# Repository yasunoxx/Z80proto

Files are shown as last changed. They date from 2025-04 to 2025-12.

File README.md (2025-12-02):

# Z80proto2 -- I/O processor, implementation for Z80

## !!!CAUTION!!!
- MiniLoaderとMiniMon-Cは、sdccに移行するための作業中です。モニタ/ローダとしてはMiniMonを使用して下さい。

## What is this?(コレは何？)
- ev68020などで使うつもりの、I/OプロセッサのZ80実装です。CP/M-68kなどの移植を視野に入れて、CP/M80を動かす事をゴールにしています。ソレゆえに、Z80proto2では64kフルRAMにする回路(ROMKICK)を含みます。

## Environment(動作環境)
Tool                    | Description
:-----------------------|:---------------------------------------------------
**target**              | Z80(Z80proto2), Z84C(SAKI80), and other Z80 compat. see sch [Z80proto/sch](https://github.com/yasunoxx/Z80proto/sch) folder
**z88dk**               | v19766-9ffe2042c-20220723
**make**                | GNU Make 4.3, Built for x86_64-pc-linux-gnu
**CAD**                 | KiCad Version (6.0.11), release build

## Status(進捗) -- 2025年4月現在
Hardware                          | Description
:---------------------------------|:-----------------------------------------
Z80proto2 board                   |設計完了, FDC&DMAモジュールの試作中
Z80proto2 SAKI80(AKA Super AKI-80) support board|設計完了, 試作回路のデバッグ中

Software           | Description
:------------------|:--------------------------------------------------------
ipl0               |デバッグ完了。MiniMonのbuildに必要
MiniMon            |MiniLoaderの拡張バージョン。ゆえにstatusはMiniLoaderと同様。機能追加中(FDC関連)&SAKI80対応作業中
MiniMon-C          |MiniMonのCバージョン。sdccに移行作業中
Miniloader         |フレームワークは完了, sdccに移行作業中

Additional         | Description
:------------------|:--------------------------------------------------------
MSP430_SPI_LCD40x4 |設計完了, SPIターゲット機能デバッグ中
freertos           |実験的実装(EXPERIMENTAL), 動作は保証しません
memtest80          |デバッグ完了。7seg表示必須(ゆえにSAKI80非対応)

## TODO(今後修正・追加すべきモノゴトと細かい話)
0. 開発環境をzccからsdccに移行する -> 現在作業中
1. SIOフロー制御の追加 -> DTR*をアサート/ネゲートするだけの機能追加、ではダメっぽいので、キチンとした仕様を実装する
2. 回路構成の説明書作成 -> プログラムの読解が困難と考えられるため早急に
3. TMPZ84C015BのSIO受信割込 -> 受信割込有効後1byteでフリーズする問題の原因特定(後述)
4. analyze_SIO0(z80sio_sub.asm)の簡略化 -> SIO0割込受信後の処理。現状はマジメにフラグをチェックしている。どうせエラーリカバリは上位で行うのだから、単にフラグクリアで良いのでは？
5. ソースコードコメンタリ作成

## Fixed Re-confirm(動作確認中の修正点)
- システムレジスタ(UW5)を74HC259などに変更する -> 現状74HC574には出力リセットが付いていないため(動作環境によっては問題になりうる)
- TC6367コンパチビリティ廃止によるUW2の削除 -> FIXしたつもりだけれども慎重に確認が必要 -> Proto2基板によりロングランテストで確認中
- 回路修正により、SPI_SELD_DEVは必要なくなった -> 7seg回路をオプションとしたため、そこに含まれていたSPICS*をシステムレジスタ(UW5)に移した -> ソレをU17で読み取り可能としたので、RAM上に保持する必要がなくなった

## Known Problem(既知の問題)
- TMPZ84C015BのSIOAにおいて、受信割込有効後1byteでフリーズする問題が起きています。現在、開発に使用しているデバイス単体の問題なのか、仕様の違いによる問題なのかの特定が出来ていません。そのため、getchar_SIO0サブルーチン(z80sio_sub.asm)でポーリング受信をしています。Z80SIOの受信バッファは3bytesなので、他の重い処理を行っている時にバッファオーバーランする可能性があります。この問題はZ80proto2基板(LH0085使用)では起きていません。
- SAKI80サポート基板において、現在の設計では使用部品の個体差(ゲート遅延など)によってRead/Writeが間に合わない場合があります。WAIT回路の追加を慎重に検討しています。現状では、アクセス時間の短いROM/RAMを選択する(55nsecでギリギリ？)、ゲート遅延の短いバッファを使用する(HCよりもVHCやABTがオススメ)などを検討してください。
- SIO送受信において、フロー制御が実装されていません。現状、ポーリング受信では取りこぼしや文字化けが発生します。ターミナル側で送信遅延(10~20msec/char)を調整すると良いようです。proto2用SIO＆CTCモジュールとSAKI80にはDTR/DSR配線が存在するので、ハードフローを実装する予定です。

## LICENSE(ライセンス)
- ソースツリーには、FreeRTOS-Kernel(FreeRTOSv202406.01-LTS)の一部が含まれています。
 [FreeRTOS/FreeRTOS](https://github.com/FreeRTOS/FreeRTOS)
- 使用しているデバイスについて、メーカーがデータシートなどで開示している技術情報は、各社に工業所有権があります。
- kermit-suspend.cは、Frank da Cruz氏によるkermit.basをCに移植したものです。
- xymodem.cは、Chuck Forsberg氏による10-14-88版ドキュメントより作成しました。
- "Super AKI-80"、"スーパーAKI-80"は、株式会社秋月電子通商の商標です。
- lcdlib.cは、Sakazume氏(http://219.117.208.26/~saka/ham/LCD2/)による実装です。
- xprintf.cは、CHaN氏(http://elm-chan.org/fsw.html)による実装の一部です。
- 私(yasunoxx▼Julia)が書いたプログラムは、MITライセンスで開示しています。本プログラム [Z80proto](https://github.com/yasunoxx/Z80proto)を使用した/使用しない事による全ての結果について、上記権利者と私は何の保証も賠償も致しません。

## FAQ(よくあるしつもん、そしてツッコミ)
- ROMを書く道具がない, ROMが入手できない -> 私は中華ROMライタ(TL866Ⅱ plus)をハードオフで拾いました。もし、どうしてもROMを入手したい(けれどもROMライタは買いたくない)という方は、私のtwitterアカウント(@noisequeen)にDMしてみて下さい。メールは殆ど読んでいません。
- ドキュメントが無いのは何故？ -> こう見えても忙しいんです。プロジェクトがスタックしているので、詳細なドキュメントは後回しになりますね。希望者が多数になったら、ドキュメント作成のプライオリティも上がりますけれども。
- 基板は作らないの？ -> こんなの、基板を起こしても。。。もし希望者多数だとしたら、秋月さんに出してほしいなぁ(その際は、可能な限りの協力を致します)。
- ソースが読みにくい -> 私の力量不足です。読みにくいと指摘できるレベルの方は、もっとエレガントなコードが書けるハズです。さあ、書いて公開するのです。ipl0やmemtest80は読みやすい部類だと思いますけれども、まだまだですね。
- FDCマダー？ -> なかなか、モチベーションが上がらないのです。CPU&CTC&SIOまではイージーなのですけれども、特にFDCは相手が物理なので。chotto mattene.

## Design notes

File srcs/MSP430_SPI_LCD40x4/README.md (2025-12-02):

MSP430_SPI_LCD40x4
==================

- SPI input, 40x4 Character LCD output for MSP430G2553.

- Add new GCC(Mitto Systems Limited - msp430-gcc 9.2.0.50) support. https://www.ti.com/tool/MSP430-GCC-OPENSOURCE

- If you use old GCC, you must edit Makefile and interrupt func.

- for usage:

    make
    mspdebug rf2500
      > prog main.elf
      > exit

- and see sources and schematics.

- ※コレは、特にどうという事の無い実装ですわね。

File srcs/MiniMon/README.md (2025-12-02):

## MiniMon -- Mini Monitor for Z80proto w/Async. FIFO

# Usage

- build ../ipl0.bin, 'zcc +embedded --no-crt ../ipl0.asm -o ../ipl0.bin'
- and just type 'make' .

# Stats(進捗状況)
- 現在、testmode(Debug via Async FIFO)の実装中です。FT245RをLinux(or wsl2)に接続して、MiniMonプロンプトに”T”コマンドを入力し、tmhost [tmhost/tm]を実行すると、FIFOを使用したハンドシェイクらしき動作をします。
- その他、実装済コマンドはMiniLoader同様に動作します。

# ## Environment(動作環境)
Tool                    | Description
:-----------------------|:---------------------------------------------------
**target**              | Z80(Z80proto2), Z84C(SAKI80), and other Z80 compat. see also sch [Z80proto/sch](https://github.com/yasunoxx/Z80proto/sch) folder
**z88dk**               | v19766-9ffe2042c-20220723
**make**                | GNU Make 4.3, Built for x86_64-pc-linux-gnu

# Memory Map
    |                   |
----:-------------------:---------------------------------
ROM | 0 ~ 0FFh          | ipl0
ROM | 100h ~ 1FFFh      | MiniMon .text & .data area
RAM | 8000h ~ 0D7FFh    | (free)
RAM | 0D800h ~ 0E7FFh   | MiniMon .text & .data area
RAM | 0E800h ~ 0F800h   | (free, but do not touch)
RAM | 0F800h ~ 0FFFFh   | MiniMon work area
RAM | (0FC30h ~ 0FFFFh) | stack

## LICENSE(ライセンス)
- 使用しているデバイスについて、メーカーがデータシートなどで開示している技術情報は、各社に工業所有権があります。
- "Super AKI-80"、"スーパーAKI-80"は、株式会社秋月電子通商の商標です。
- lcdlib.cは、Sakazume氏(http://219.117.208.26/~saka/ham/LCD2/)による実装です。
- 私(yasunoxx▼Julia)が書いたプログラムは、MITライセンスで開示しています。本プログラム[Z80proto](https://github.com/yasunoxx/Z80proto)を使用した/使用しない事による全ての結果について、上記権利者と私は何の保証も賠償も致しません。

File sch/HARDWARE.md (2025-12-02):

# Z80proto2 hardware -- I/O processor, implementation for Z80

## What is this?(コレは何？)
- ev68020などで使うつもりの、I/OプロセッサのZ80実装です。ここでは、ハードウェアの概要を説明します。

## Environment(動作環境)
Tool                    | Description
:-----------------------|:---------------------------------------------------
**target**              | Z80(Z80proto2), Z84C(SAKI80), and other Z80 compat.
**Boot ROM**            | 2716/2816 for minimum config., 2764/2864 for Serial Download config.
**CAD**                 | KiCad Version (6.0.11), release build

## Directory(ディレクトリ構成)
Directory           | Description
:-------------------|:--------------------------------------------------
**FDC**             |MZ-80FI's diagram trace (C)1981 Sharp Corporation
**MZ80K_framebuf**  |MZ-80K's diagram trace (C)1979-81 Sharp Corporation
**Z80proto1**       |Z80proto IM1 model(project suspend)
**Z80proto2**       |Z80proto IM2 model
**Z80proto2-SAKI80**|Z80proto IM2 model w/Super AKI-80

## Status(進捗) -- 2025年4月現在
- Z80proto2基板 -> 設計完了, FDC&DMAモジュールの試作中
- Z80proto2 SAKI80(AKA Super AKI-80)サポート基板 -> 設計完了, 試作回路のデバッグ中

## Overview(概要)
- 全体的には、ごく普通のZ80回路です。クロック4MHzで150nsecのメモリがノーウェイト動作しています。SAKI80の場合は1ウェイト入れておくべきでしょう。
- 本設計の最大の特徴はROMKICK回路です。コレは、ROM領域をI/O操作によりRAMに切り替え可能としたもので、他のプロジェクトでも動作の実績があります。下記メモリマップを参照して下さい。
- 本プロジェクト(Z80proto)開始時に、東京秋葉原で容易に入手可能なRAMは容量が大きなモノばかりだったので、628128相当のM68AF127を採用しました。Z80のメモリ空間64kBytesの2倍なので、リセット後には領域の前半分64kBytesを使い、RAMKICK回路により切り替え可能としています。
- ROMKICK/RAMKICKについて。プログラム誤動作などによる切り替え動作を防ぐため、2ステップの手順が必要です。
- その他、ソフトウェアによるSPI実装(ソレに対応するI/Oピン)、7seg LED表示機能(オプション)があります。
- ROMKICK/RAMICK, SPI機能を使用しない場合は、回路を実装しなくても構いません。ROMのアドレスデコードは忘れずに。

## Memory Map(メモリマップ)
- Power or RESET*　on Z80proto2
Address    |
:----------|:--------------------------------
0000h~1FFFh| ROM
2000h~FFFFh| RAM前半 or 後半(RAMKICKで切り替え)

- ROMKICK操作後
Address    |
:----------|:--------------------------------
0000h~FFFFh| RAM前半 or 後半(RAMKICKで切り替え)

-- ROMKICK後、フルRAM状態でRAMKICKする際には、当然ながら工夫が必要です。

## TODO(今後修正・追加すべきモノゴトと細かい話)
1. 回路構成の説明書作成 -> この文書。書き足していきます
2. TC6367コンパチビリティ廃止によるUW2の削除 -> FIXしたつもりだけれども慎重に確認が必要 -> Proto2基板によりロングランテストで確認中
3. 回路修正により、SPI_SELD_DEVは必要なくなった -> 7seg回路をオプションとしたため、そこに含まれていたSPICS*をシステムレジスタ(UW5)に移した -> ソレをU17で読み取り可能としたので、RAM上に保持する必要がなくなった
4. システムレジスタ(UW5)を74HC259などに変更する -> 現状74HC574には出力リセットが付いていないため(動作環境によっては問題になりうる)

## Known Problem(既知の問題)
-  SAKI80サポート基板において、現在の設計では使用部品の個体差(ゲート遅延など)によってRead/Writeが間に合わない場合があります。WAIT回路の追加を慎重に検討しています。現状では、アクセス時間の短いROM/RAMを選択する(55nsecでギリギリ？)、ゲート遅延の短いバッファを使用する(HCよりもVHCやABTがオススメ)などを検討してください。

## Cautions(注意事項)
- 28C64を使用する場合、2764との差異により1番ピンの処置が必要になります。

## LICENSE(ライセンス)
- FDC回路の設計参考として、MZ-80KとMZ-80FIの回路図を参照させて頂きました。(C)1979-81 Sharp Corporation
- 使用しているデバイスについて、メーカーがデータシートなどで開示している技術情報は、各社に工業所有権があります。
- "Super AKI-80"、"スーパーAKI-80"は、株式会社秋月電子通商の商標です。
- 私(yasunoxx▼Julia)が書いたプログラムは、MITライセンスで開示しています。本プログラム [Z80proto2](https://github.com/yasunoxx/Z80proto2)を使用した/使用しない事による全ての結果について、上記権利者と私は何の保証も賠償も致しません。

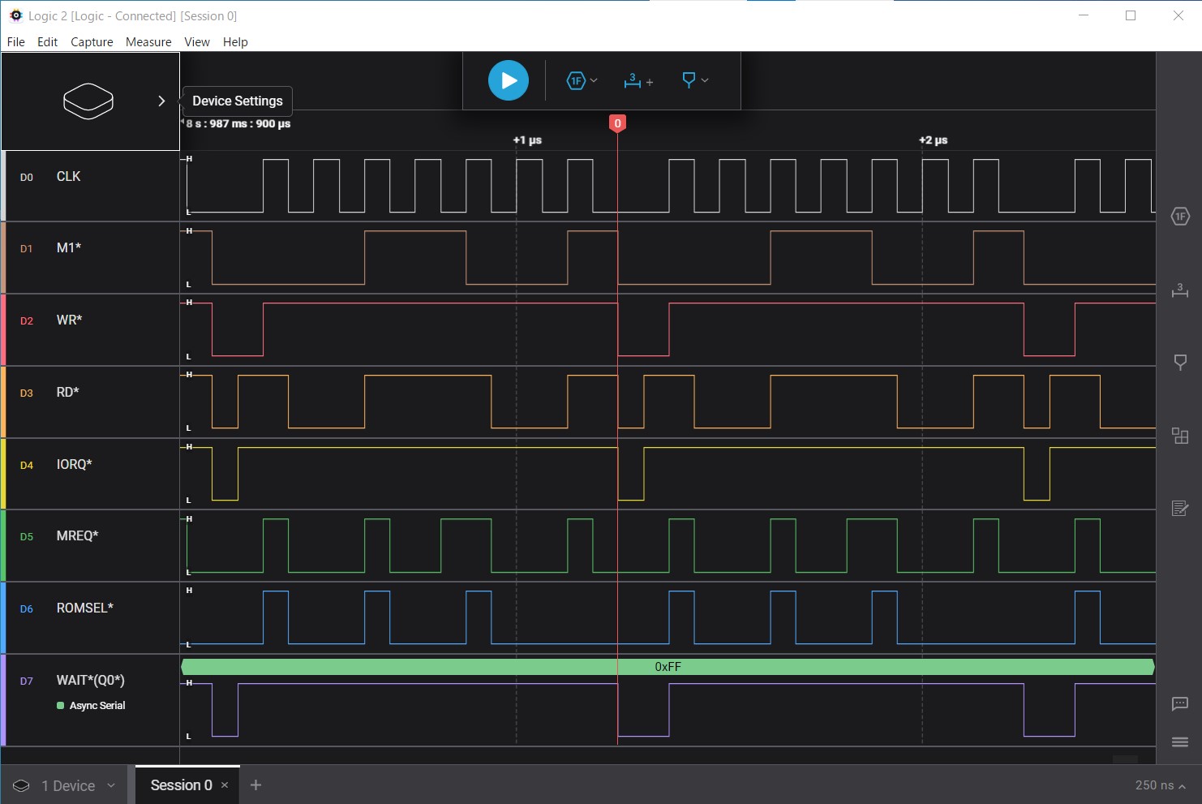
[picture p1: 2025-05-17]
sch/Z80proto-SAKI80/スクリーンショット 2025-05-12 010213.jpg

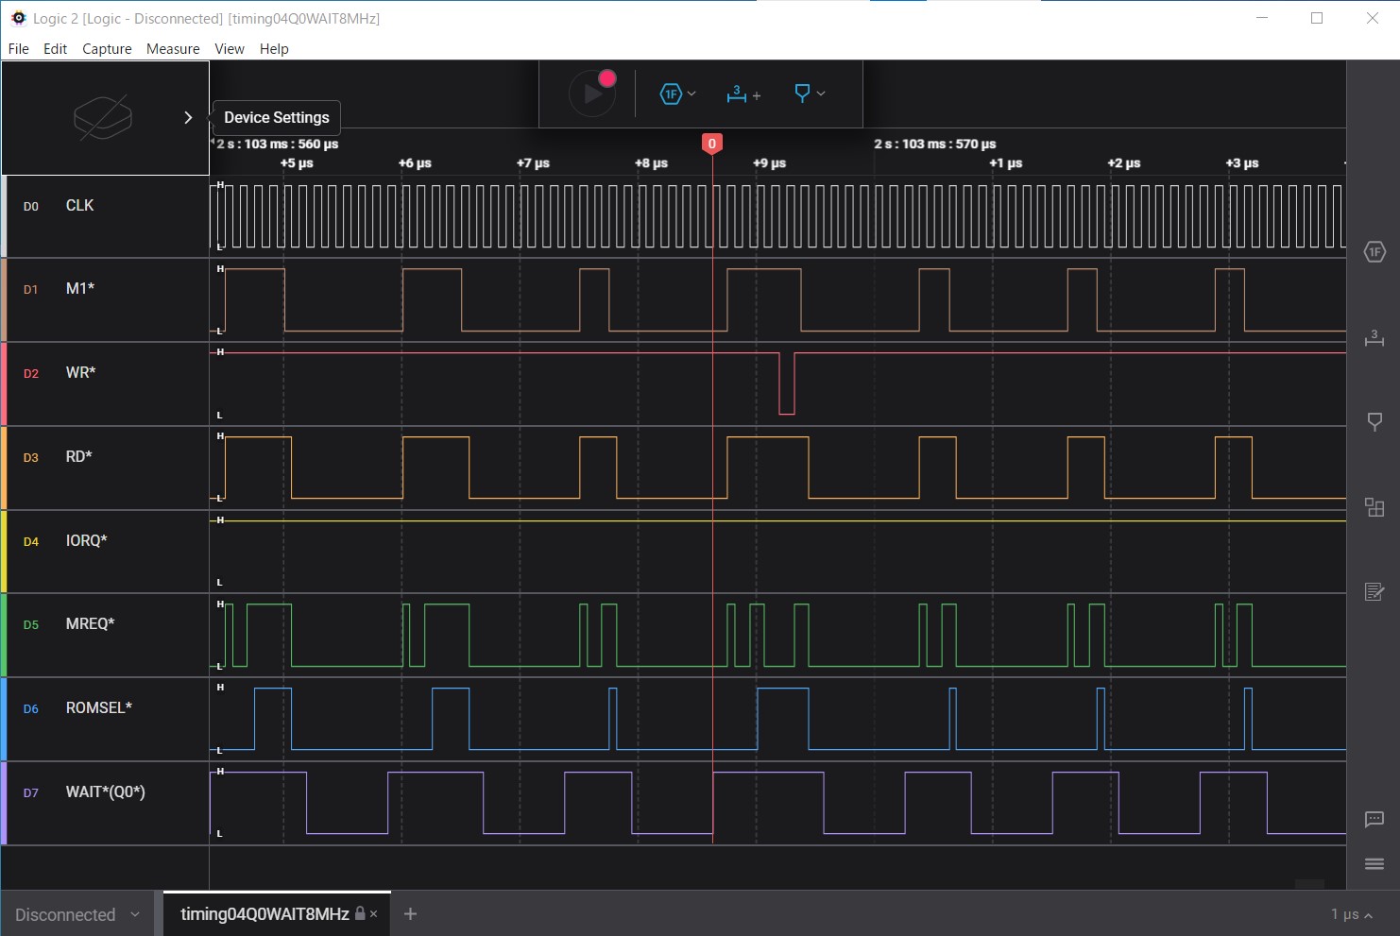
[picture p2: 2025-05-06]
sch/Z80proto-SAKI80/timing04Q0WAIT8MHz.jpg

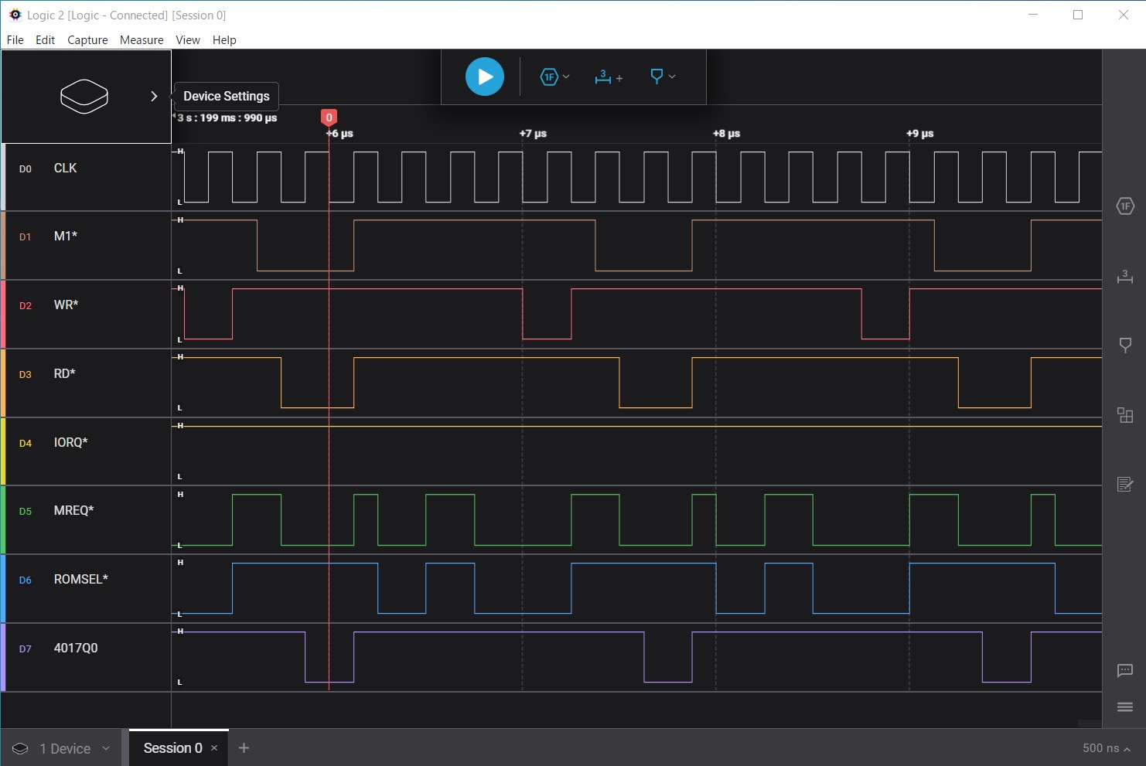
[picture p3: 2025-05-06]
sch/Z80proto-SAKI80/timing04Q0.jpg

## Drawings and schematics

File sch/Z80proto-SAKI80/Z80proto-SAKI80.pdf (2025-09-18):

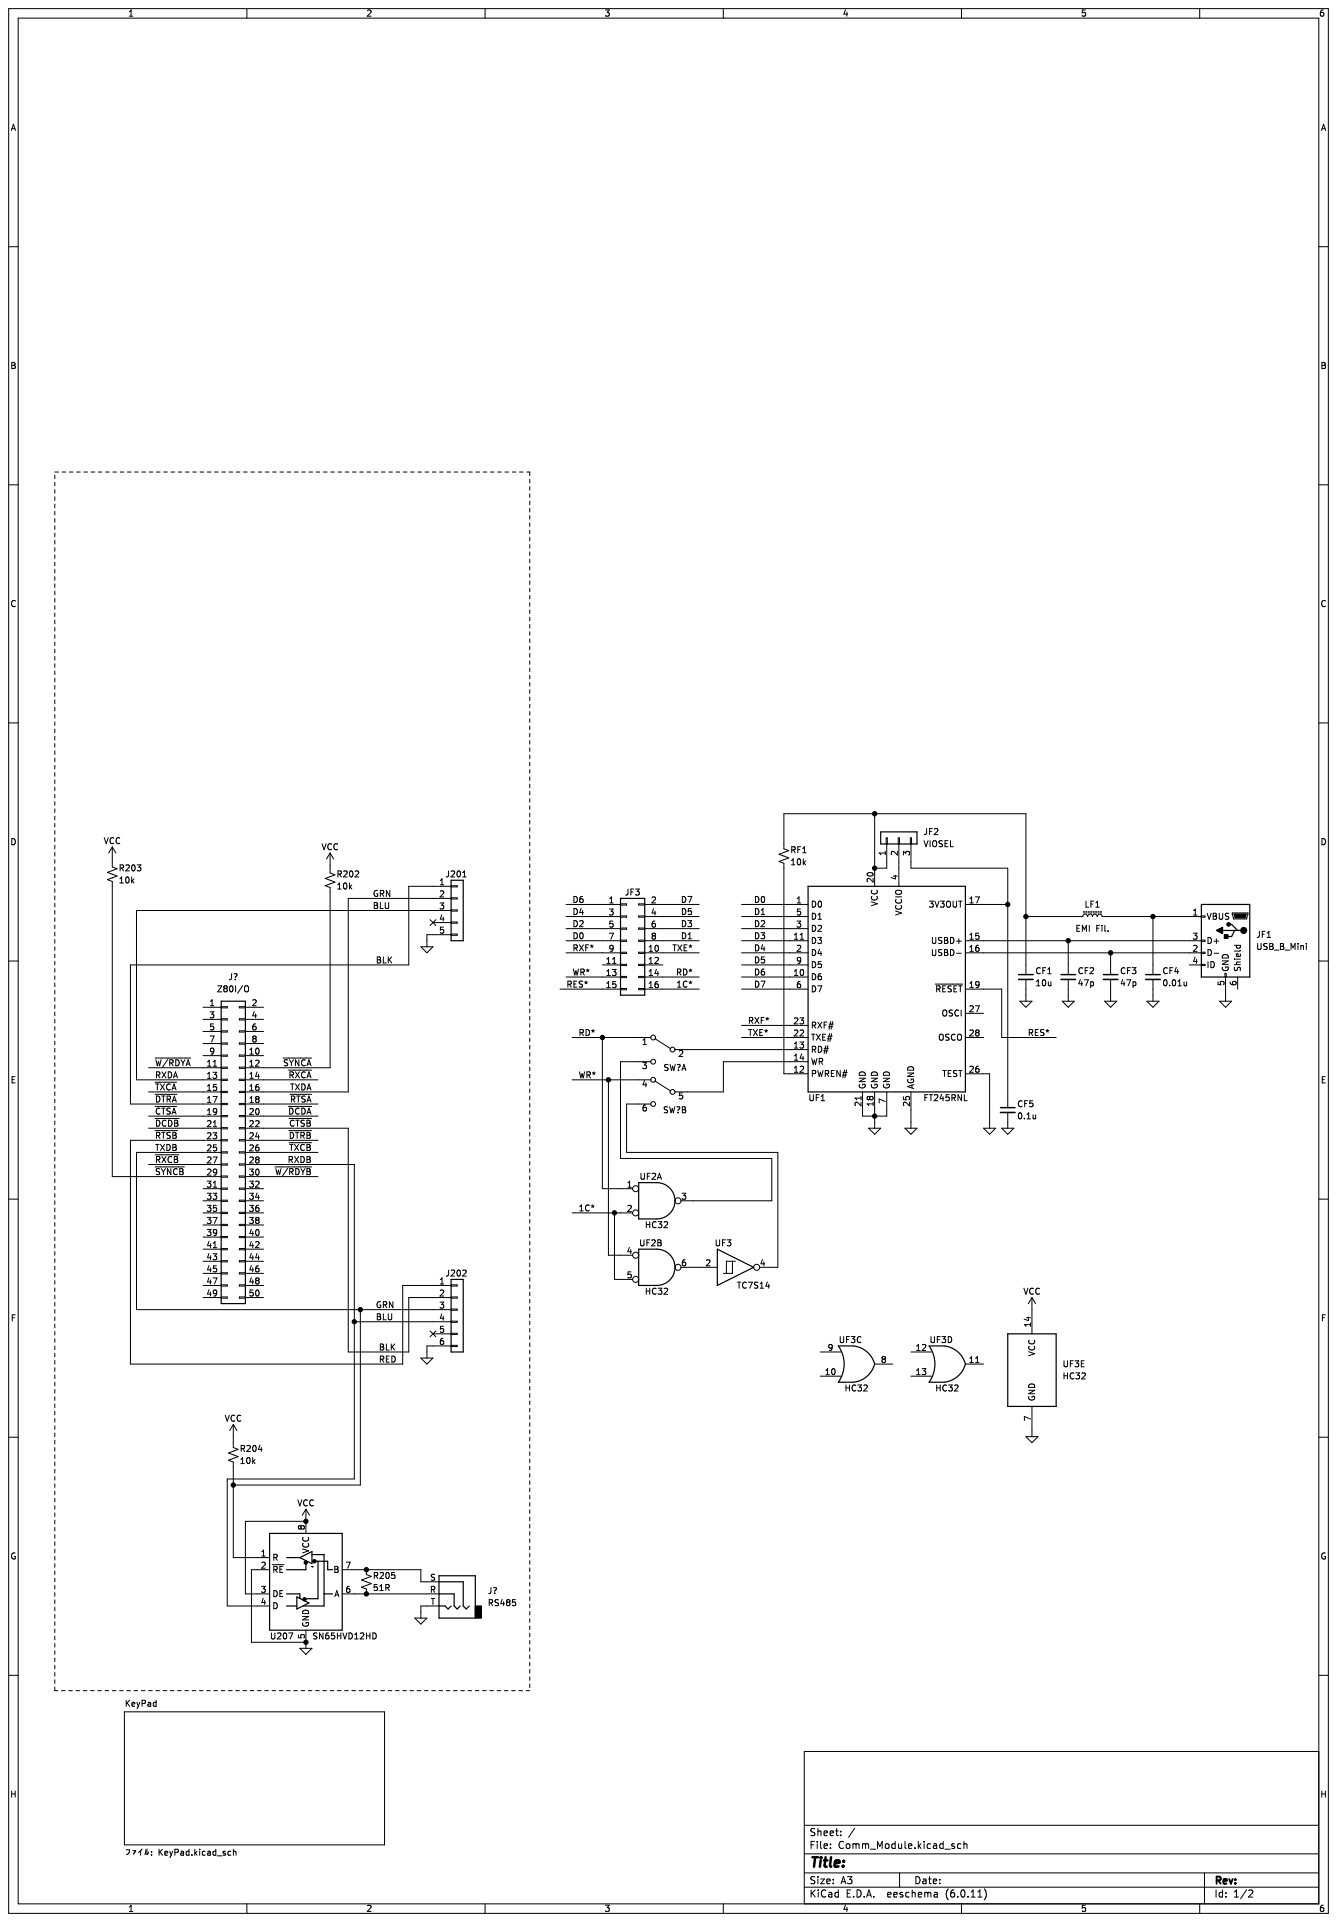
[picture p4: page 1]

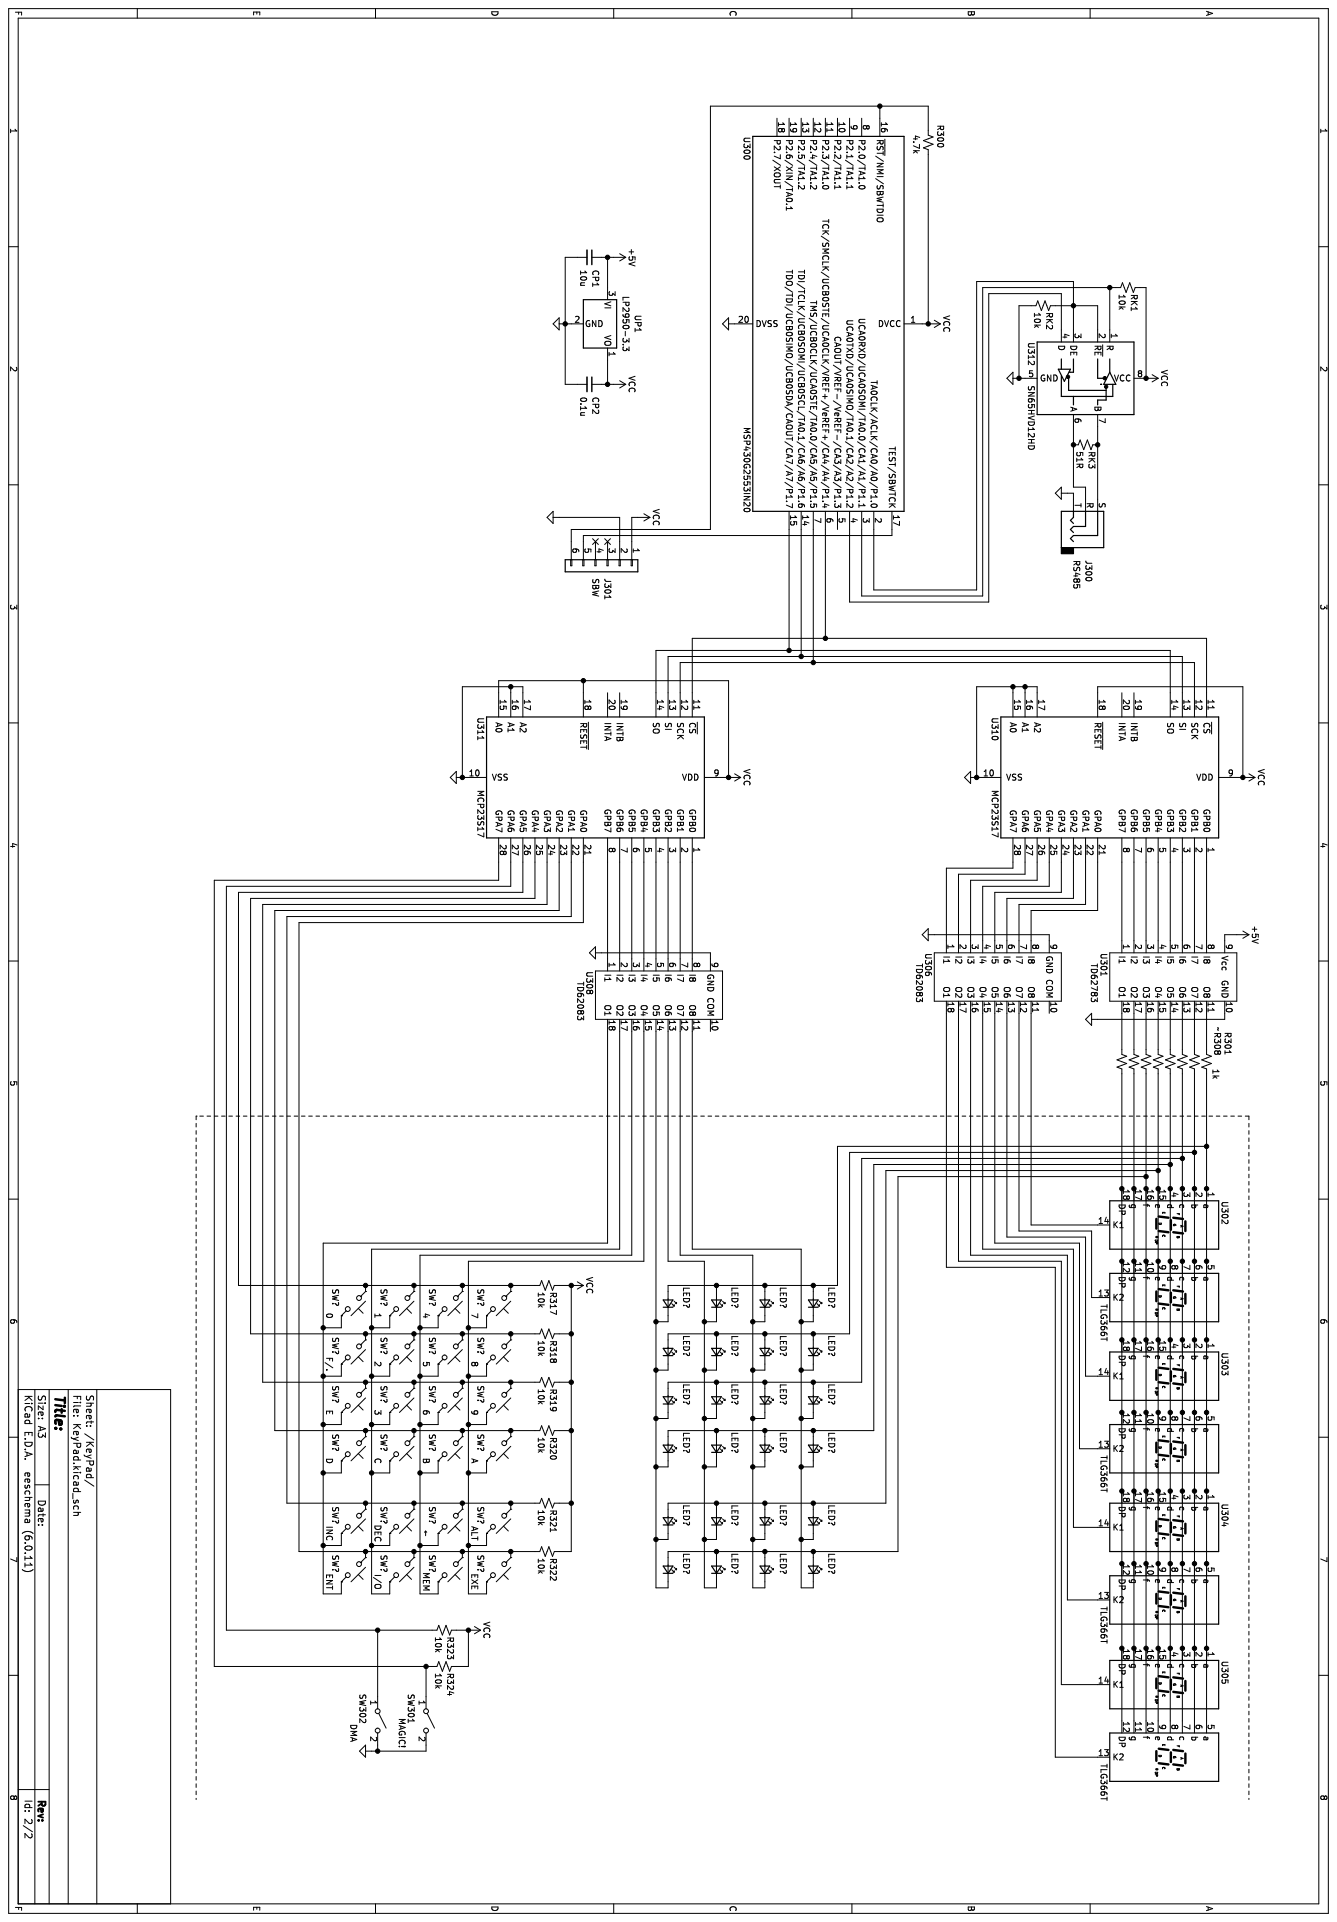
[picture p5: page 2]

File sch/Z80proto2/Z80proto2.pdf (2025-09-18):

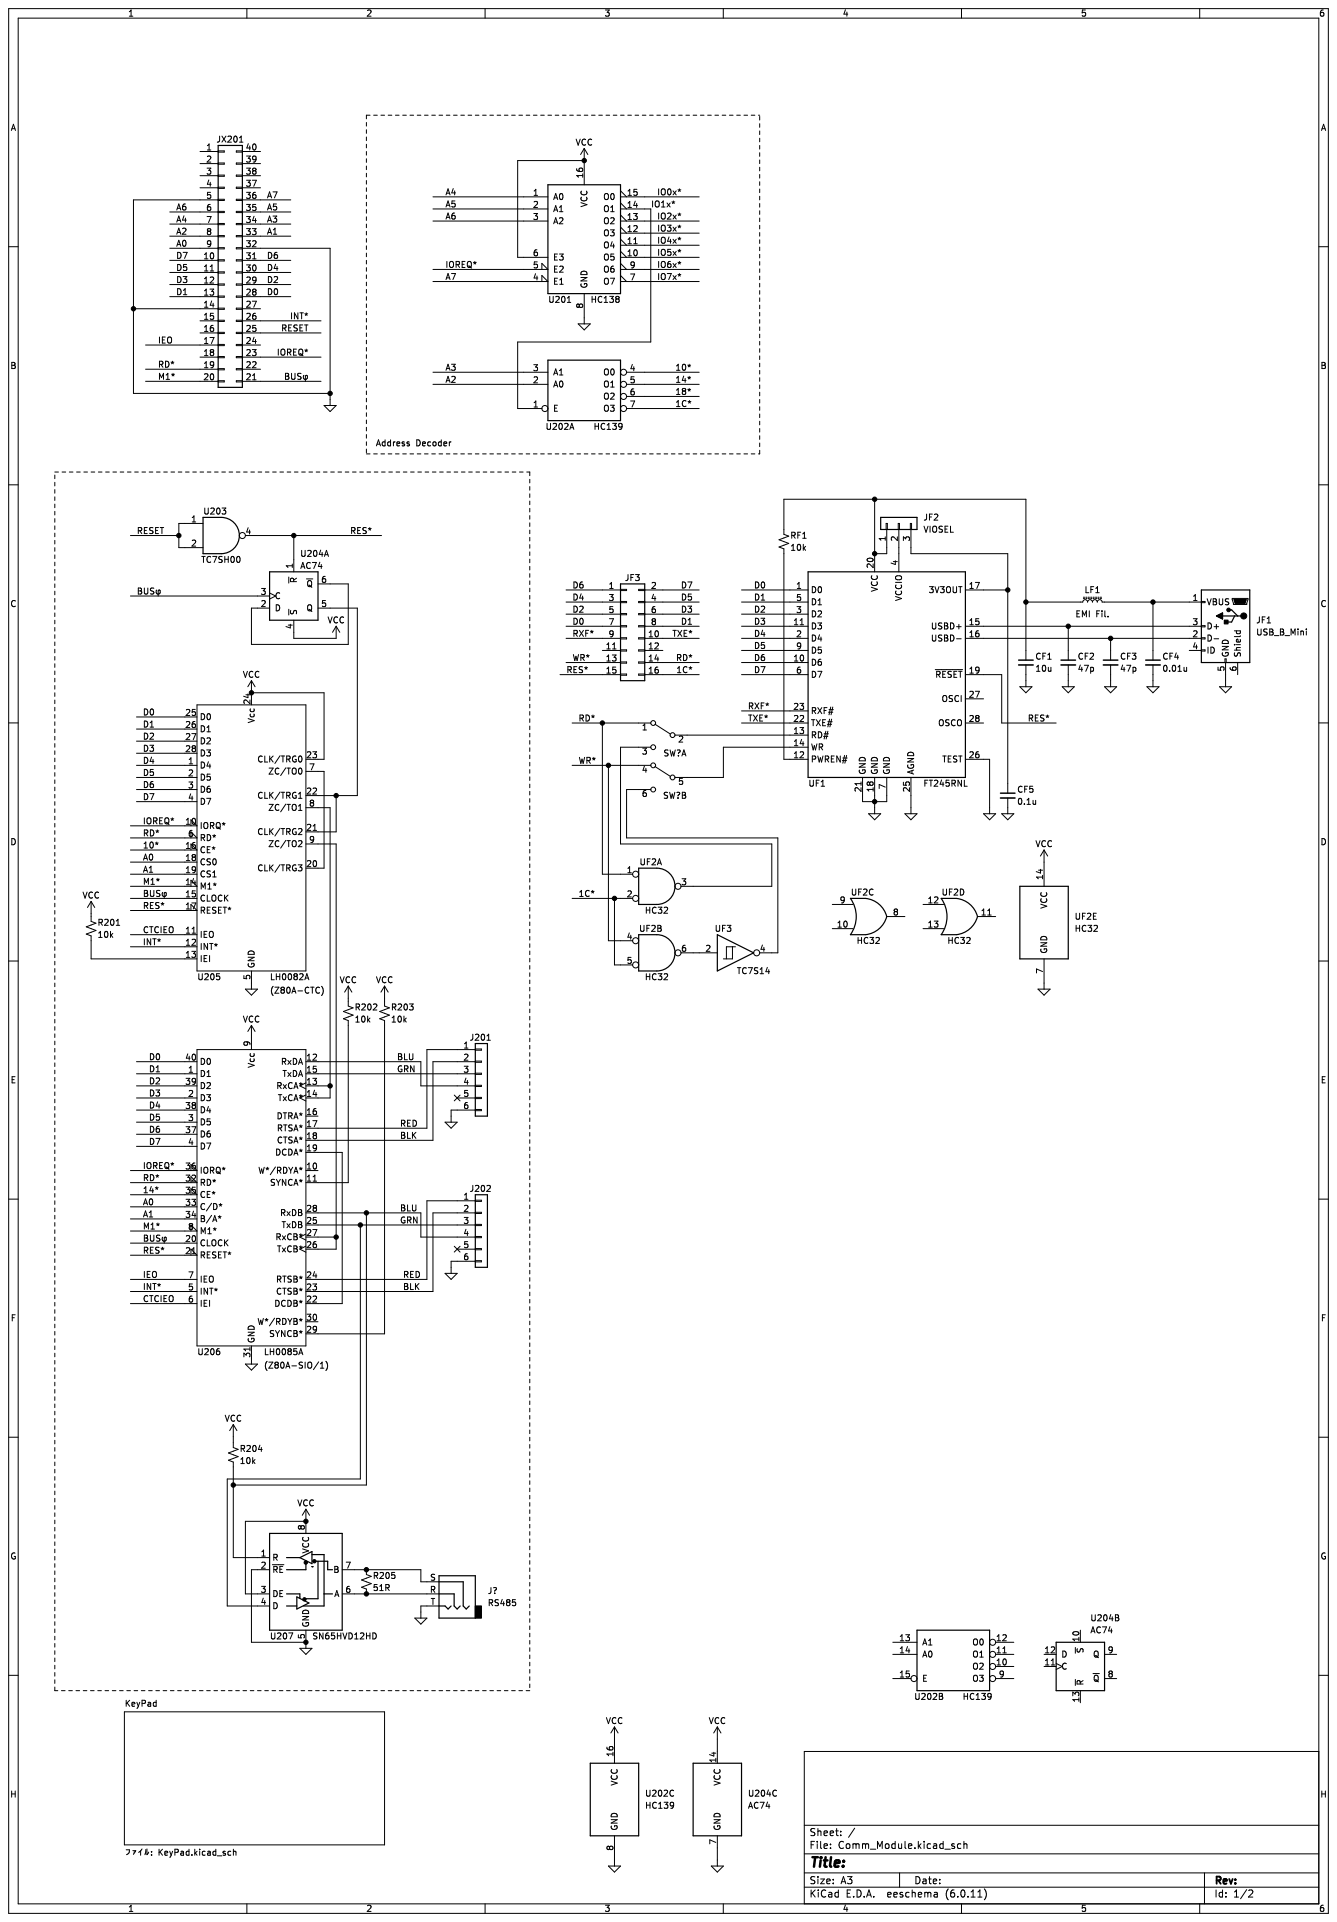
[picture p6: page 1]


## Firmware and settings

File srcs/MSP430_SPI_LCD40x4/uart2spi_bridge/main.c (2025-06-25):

/* --COPYRIGHT--,BSD_EX
 * Copyright (c) 2017, Texas Instruments Incorporated
 * All rights reserved.
 *
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
 * *  Redistributions of source code must retain the above copyright
 *    notice, this list of conditions and the following disclaimer.
 *
 * *  Redistributions in binary form must reproduce the above copyright
 *    notice, this list of conditions and the following disclaimer in the
 *    documentation and/or other materials provided with the distribution.
 *
 * *  Neither the name of Texas Instruments Incorporated nor the names of
 *    its contributors may be used to endorse or promote products derived
 *    from this software without specific prior written permission.
 *
 * THIS SOFTWARE IS PROVIDED BY THE COPYRIGHT HOLDERS AND CONTRIBUTORS "AS IS"
 * AND ANY EXPRESS OR IMPLIED WARRANTIES, INCLUDING, BUT NOT LIMITED TO,
 * THE IMPLIED WARRANTIES OF MERCHANTABILITY AND FITNESS FOR A PARTICULAR
 * PURPOSE ARE DISCLAIMED. IN NO EVENT SHALL THE COPYRIGHT OWNER OR
 * CONTRIBUTORS BE LIABLE FOR ANY DIRECT, INDIRECT, INCIDENTAL, SPECIAL,
 * EXEMPLARY, OR CONSEQUENTIAL DAMAGES (INCLUDING, BUT NOT LIMITED TO,
 * PROCUREMENT OF SUBSTITUTE GOODS OR SERVICES; LOSS OF USE, DATA, OR PROFITS;
 * OR BUSINESS INTERRUPTION) HOWEVER CAUSED AND ON ANY THEORY OF LIABILITY,
 * WHETHER IN CONTRACT, STRICT LIABILITY, OR TORT (INCLUDING NEGLIGENCE OR
 * OTHERWISE) ARISING IN ANY WAY OUT OF THE USE OF THIS SOFTWARE,
 * EVEN IF ADVISED OF THE POSSIBILITY OF SUCH DAMAGE.
 *
 *******************************************************************************
 *
 *                       MSP430 CODE EXAMPLE DISCLAIMER
 *
 * MSP430 code examples are self-contained low-level programs that typically
 * demonstrate a single peripheral function or device feature in a highly
 * concise manner. For this the code may rely on the device's power-on default
 * register values and settings such as the clock configuration and care must
 * be taken when combining code from several examples to avoid potential side
 * effects. Also see www.ti.com/grace for a GUI- and www.ti.com/msp430ware
 * for an API functional library-approach to peripheral configuration.
 *
 * --/COPYRIGHT--*/
//******************************************************************************
//  MSP430FR2000 Demo - UART-to-SPI Bridge
//
//  Description: This example enables serial communication between a UART device
//  and a SPI device. The hardware SPI interface utilizes the
//  eUSCI_A module, and the software (SW) UART interface utilizes Timer_B.
//  Connect the SPI device to the SPI interface
//  (P1.5, P1.6 and P1.7), and connect the UART device to the
//  SW UART interface (P2.0 and P2.1). This example supports half-duplex
//  UART communication only, eight data bits with least significant bit first,
//  no parity bit, and one stop bit. After initializing everything, the CPU
//  waits in LPM0 to save power until a SPI or UART receive interrupt occurs.
// Then, the CPU exits LPM0, reads the SPI or UART data, transmits the data on
//  the other interface, and returns to LMP0.
//  ACLK = default REFO ~32768Hz, MCLK = SMCLK = 16MHz
//
//                               MSP430FR2000
//                           -------------------
//                       /|\|                   |
//                        | |                   |
//                        --|RST                |
//                          |                   |
//               SPI CLK <--|P1.5/UCA0CLK       |
//                          |                   |
//              SPI MISO -->|P1.6/UCA0SOMI  P2.0|--> SW UART TX Out
//                          |                   |
//              SPI MOSI <--|P1.7/UCA0SIMO  P2.1|<-- SW UART RX In
//                          |                   |
//                          |                   |
//
//
//  Nathan Siegel
//  Texas Instruments Inc.
//  Sept. 2017
//  Built with IAR Embedded Workbench v7.10.2 & Code Composer Studio v7.2.0
//******************************************************************************

#include <msp430g2553.h>
#include <stdint.h>
#include <stdbool.h>
#include "io.h"
#include "tlv.h"
#include "spi_target.h"
#include "lcd.h"

const char *FW_Version = "0X01";

// Define pins
#define SPI_MOSI_PIN  BIT7      // SPI transmit pin, P1.7
#define SPI_MISO_PIN  BIT6      // SPI receive pin,  P1.6
#define SPI_CLK_PIN BIT5      // SPI CLK pin, P1.5
#define SW_TX_PIN   BIT0      // SW UART transmit pin, P2.0
#define SW_RX_PIN   BIT1      // SW UART receive pin,  P2.1

// Define parameters
#define SW_WHOLE_BIT 1666   // Full bit time, units are in clock cycles
                            // SW_WHOLE_BIT = SMCLK/SW UART baud rate
                            //              = 16MHz/9600 baud, SMCLK = 16MHz
                            //              = 1666 cycles

#define SW_HALF_BIT  833    // Half bit time, units are in clock cycles
                            // SW_HALF_BIT = SW_WHOLE_BIT/2 = 1666/2
                            //             = 833 cycles

#define SW_TOTAL_BITS 9     // 1 start bit, 8 data bits, 1 stop bit

// Define states
#define SPI_RX_STATE 1       // HW SPI receive state
#define SW_RX_STATE 2       // SW UART receive state

// Declare global variables
#if defined (__TI_COMPILER_VERSION__)
volatile uint16_t tempByte;                    // Stores data byte
volatile uint8_t bitCounter;                   // Tracks number of bits
volatile unsigned char currentState;           // Used to indicate state

#elif defined (__IAR_SYSTEMS_ICC__)
__no_init volatile uint16_t tempByte;          // Stores data byte
__no_init volatile uint8_t bitCounter;         // Tracks number of bits
__no_init volatile unsigned char currentState; // Used to indicate state
#endif

#define TIMER_PWM_PERIOD 12
#define TIMER_PWM_PERIOD_DCO 12000
void ConfigureTimerPwm( void );
void PreApplicationMode( void );
void InitializeClocks( void );
void initializeDCO( void );
void InitializeLeds( void );

#define SYSTIMER_COUNTUP        100
volatile unsigned int SysTimer_Counter;
#define SYSTIMER2_COUNTUP       10
volatile unsigned int SysTimer2_Counter;
#define Low 0
#define High 1
volatile unsigned char ClockMode;

#define SYSTIMER_FLIP_OFF       0
#define SYSTIMER_FLIP_ON        1
volatile unsigned char F_SysTimer_Flipper;
#define SYSTIMER2_FLIP_OFF      0
#define SYSTIMER2_FLIP_ON       1
volatile unsigned char F_SysTimer2_Flipper;

// Declare functions
void ConfigureTimerPwm( void )
{
    if( ClockMode == Low )
    {
        TACCR0 = TIMER_PWM_PERIOD;          // Compare Maxim value
        #ifdef TARGET_XT1
            TACTL = TASSEL_2 | MC_1;        // TACLK = SMCLK, Up mode.
        #else
            TACTL = TASSEL_2 | MC_1;        // TACLK = ACLK, Up mode.
        #endif
        TACCTL0 = CCIE;                     // TACCTL0 output OUT bit(not used)
        TACCTL1 = CCIE + OUTMOD_3;          // TACCTL1 Capture Compare, Set/reset
    }
    else // ClockMode Low to High
    {
        TACCR0 = TIMER_PWM_PERIOD_DCO;      // Compare Maxim value
        TACTL = TASSEL_2 | MC_1;            // TACLK = SMCLK, Up mode.
        TACCTL0 = CCIE;                     // TACCTL0 output OUT bit(not used)
        TACCTL1 = CCIE + OUTMOD_3;          // TACCTL1 Capture Compare, Set/reset
    }                                              
}

void InitializeClocks( void )
{
    DCOCTL = 0;
    BCSCTL1 = 0;
    BCSCTL1 = XT2OFF | DIVA_0 | RSEL0;
                      // Set ACLK / 1
    BCSCTL2 = 0;
    BCSCTL2 = SELM_3 | DIVM_0 | SELS | DIVS_0;
                      // SMCLK = MCLK = ACLK = 12kHz
    BCSCTL3 = 0;
    BCSCTL3 = LFXT1S_2; // use VLO    
}

void initializeDCO( void )
{
        DCOCTL = Var_CALDCO_16MHz;
        DCOCTL |= DCO2;
        BCSCTL1 = Var_CALBC1_16MHz;
        BCSCTL1 |= DIVA_0;
        BCSCTL2 &= ~( DIVS_3 );
        BCSCTL2 = SELM_0 | DIVM_0; // DCO = MCLK = SMCLK = ACLK(12MHZ, VLO * 1000)
        TACTL = TASSEL_2 | MC_2 | TACLR;
      // Select SMCKL as source, no divider, Continuous mode and reset timer
        BCSCTL1 |= XT2OFF; // XT2 off, and Set ACLK to /1 divider

        ClockMode = High;
}

void PreApplicationMode( void )
{
        SysTimer_Counter = 0;
        F_SysTimer_Flipper = SYSTIMER_FLIP_OFF;
        SysTimer2_Counter = 0;
        F_SysTimer2_Flipper = SYSTIMER2_FLIP_OFF;
        ClockMode = Low;
//  __bis_SR_register( LPM3_bits + GIE );  // LPM0 with
//  __bis_SR_register( LPM3_bits );
}

// Main function
int main(void)
{
    WDTCTL = WDTPW | WDTHOLD;       // Stop watchdog timer
    ClockMode = Low;

    InitializeClocks();
    InitializeIOpins();
    PreApplicationMode();
    ConfigureTimerPwm();

    __enable_interrupt();
    ConfigureAdcTempSensor();
    GetTLV();
    __disable_interrupt();
    initializeDCO(); // on this file
    ConfigureTimerPwm();
    __enable_interrupt();

#ifdef FIXME
    // Initialize hardware UART pins
    P1SEL0 |= SPI_MISO_PIN | SPI_MOSI_PIN | SPI_CLK_PIN;      // Select SPI function

    // Initialize software UART pins, terminate unused GPIOs
    PADIR = 0xC1FF;                       // P2DIR = PADIR_H, P1DIR = PADIR_L
                                          // SW_TX_PIN (P2.0) = output
                                          // SW_RX_PIN (P2.1) = input

    PAOUT = 0x0100;                       // High (set UART idle state)
                                          // P2OUT = PAOUT_H, P1OUT = PAOUT_L
                                          // SW_TX_PIN (P2.0) = high

    P2IES |= SW_RX_PIN;                   // Select high-to-low interrupt edge
    P2IFG &= ~SW_RX_PIN;                  // Clear interrupt flag
    P2IE |= SW_RX_PIN;                    // Enable interrupt

    // Configure eUSCI_A SPI module
    UCA0CTLW0 = UCSWRST | UCSSEL__ACLK | UCMST | UCSYNC;  // Reset eUSCI
                                                           // Set SMCLK as BRCLK source
                                                           // Select master mode
                                                           // Enable Synchronous mode

    UCA0BRW = 0x0002;               // Bit rate clock = SMCLK/2 = 8 MHz

    UCA0CTLW0 &= ~UCSWRST;          // Release eUSCI_A UART module for operation
    UCA0IE = UCRXIE;                // Enable eUSCI_A RX interrupt
#endif

    // Enable global interrupts and enter LPM0
    __bis_SR_register(LPM0_bits + GIE);
}

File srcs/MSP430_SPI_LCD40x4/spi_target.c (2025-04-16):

/*
 * spi_target.c -- SPI and 40x4 Char. LCD for MSP430G2553
 * (C)2021,2022,2025 by yasunoxx▼Julia
 * ### Use TI-MSPGCC6.1.1.0 or above version ###
 */

/* Original Source Copyright and usage */
//******************************************************************************
//   MSP430G2xx3 Demo - USCI_B0, SPI 3-Wire Master multiple byte RX/TX
//
//   Description: SPI master communicates to SPI slave sending and receiving
//   3 different messages of different length. SPI master will enter LPM0 mode
//   while waiting for the messages to be sent/receiving using SPI interrupt.
//   SPI Master will initially wait for a port interrupt in LPM0 mode before
//   starting the SPI communication.
//   ACLK = NA, MCLK = SMCLK = DCO 16MHz.
//
//   Nima Eskandari
//   Texas Instruments Inc.
//   April 2017
//   Built with CCS V7.0
//
// and Modified by yasunoxx 2021/2022
//
//                   MSP430G2553
//                 -----------------
//            /|\ |                 |
//             |  |                 |
//             ---|RST          *RST|-> Target Reset (*RST)
//                |                 |
//                |             P1.2|-> Data Out (UCA0SIMO)
//                |                 |
//          LED <-|P1.7         P1.1|<- Data In (UCA0SOMI)
//                |                 |
//                |             P1.4|-> Serial Clock In (UCA0CLK)
//
//******************************************************************************

#include <msp430g2553.h>
#include <stdint.h>
#include <stdio.h>
#include "spi_target.h"
#include "lcd.h"

#define	INITSTAT_BUSY	0x80
#define	INITSTAT_READY	0
extern  volatile unsigned char F_InitStat;  // main.c

/* MasterTypeX are example buffers initialized in the master, they will be
 * sent by the master to the slave.
 * TargetTypeX are example buffers initialized in the slave, they will be
 * sent by the slave to the master.
 * */

uint8_t MasterType0 [TYPE_M0_LENGTH] = { 0 };
uint8_t MasterType1 [TYPE_M1_LENGTH] = { 0 };
uint8_t MasterType2 [TYPE_M2_LENGTH] = { 0 };

uint8_t TargetType0 [TYPE_T0_LENGTH] = { NAK };
uint8_t TargetType1 [TYPE_T1_LENGTH] = { NAK };
uint8_t TargetType2 [TYPE_T2_LENGTH] = { NAK };

/* Used to track the state of the software state machine*/
SPI_Mode TargetMode = RX_REG_ADDRESS_MODE;

/* The Register Address/Command to use*/
uint8_t ReceiveRegAddr = 0;

/* ReceiveBuffer: Buffer used to receive data in the ISR
 * RXByteCtr: Number of bytes left to receive
 * ReceiveIndex: The index of the next byte to be received in ReceiveBuffer
 * TransmitBuffer: Buffer used to transmit data in the ISR
 * TXByteCtr: Number of bytes left to transfer
 * TransmitIndex: The index of the next byte to be transmitted in TransmitBuffer
 * */
uint8_t ReceiveBuffer[MAX_BUFFER_SIZE];
uint8_t RXByteCtr = 0;
uint8_t ReceiveIndex = 0;
uint8_t TransmitBuffer[MAX_BUFFER_SIZE];
uint8_t TXByteCtr = 0;
uint8_t TransmitIndex = 0;

/* Initialized the software state machine according to the received cmd
 *
 * cmd: The command/register address received
 * */
void SPI_Target_ProcessCMD(uint8_t cmd);

/* The transaction between the slave and master is completed. Uses cmd
 * to do post transaction operations. (Place data from ReceiveBuffer
 * to the corresponding buffer based in the last received cmd)
 *
 * cmd: The command/register address corresponding to the completed
 * transaction
 */
void SPI_Target_TransactionDone(uint8_t cmd);
void CopyArray(uint8_t *source, uint8_t *dest, uint8_t count);
void SendUCA0Data(uint8_t val);

void SPI_Target_ProcessCMD(uint8_t cmd)
{
    ReceiveIndex = 0;
    TransmitIndex = 0;
    RXByteCtr = 0;
    TXByteCtr = 0;

    switch (cmd)
    {
        case (CMD_TYPE_0_TARGET):   //Send slave stat (This device's id)
            BufLCD[ 3 ][ 0 ] = 'X';
            TargetMode = TX_DATA_MODE;
            TXByteCtr = TYPE_T0_LENGTH;
            //Fill out the TransmitBuffer
            TargetType0[ 0 ] = ACK;
            CopyArray(TargetType0, TransmitBuffer, TYPE_T0_LENGTH);
            //Send First Byte
            SendUCA0Data(TransmitBuffer[TransmitIndex++]);
            TXByteCtr--;
            break;
        case (CMD_TYPE_1_TARGET):   //Send slave device time (This device's time)
            TargetMode = TX_DATA_MODE;
            TXByteCtr = TYPE_T1_LENGTH;
            //Fill out the TransmitBuffer
            CopyArray(TargetType1, TransmitBuffer, TYPE_T1_LENGTH);
            //Send First Byte
            SendUCA0Data(TransmitBuffer[TransmitIndex++]);
            TXByteCtr--;
            break;
        case (CMD_TYPE_2_TARGET):   //Send slave device location (This device's location)
            TargetMode = TX_DATA_MODE;
            TXByteCtr = TYPE_T2_LENGTH;
            //Fill out the TransmitBuffer
            CopyArray(TargetType2, TransmitBuffer, TYPE_T2_LENGTH);
            //Send First Byte
            SendUCA0Data(TransmitBuffer[TransmitIndex++]);
            TXByteCtr--;
            break;
        case (CMD_TYPE_0_MASTER):
            TargetMode = RX_DATA_MODE;
            RXByteCtr = TYPE_M0_LENGTH;
            break;
        case (CMD_TYPE_1_MASTER):
            TargetMode = RX_DATA_MODE;
            RXByteCtr = TYPE_M1_LENGTH;
            break;
        case (CMD_TYPE_2_MASTER):
            TargetMode = RX_DATA_MODE;
            RXByteCtr = TYPE_M2_LENGTH;
            break;
        default:
            __no_operation();
            break;
    }
}


void SPI_Target_TransactionDone(uint8_t cmd)
{
    switch (cmd)
    {
        case (CMD_TYPE_0_TARGET): //Target device id was sent(This device's id)
            break;
        case (CMD_TYPE_1_TARGET): //Target device time was sent(This device's time)
            break;
        case (CMD_TYPE_2_TARGET): //Send slave device location (This device's location)
            break;
        case (CMD_TYPE_0_MASTER):
            CopyArray(ReceiveBuffer, MasterType0, TYPE_M0_LENGTH);
            break;
        case (CMD_TYPE_1_MASTER):
            CopyArray(ReceiveBuffer, MasterType1, TYPE_M1_LENGTH);
            break;
        case (CMD_TYPE_2_MASTER):
            CopyArray(ReceiveBuffer, MasterType2, TYPE_M2_LENGTH);
            break;
        default:
            __no_operation();
            break;
    }
}

void CopyArray(uint8_t *source, uint8_t *dest, uint8_t count)
{
    uint8_t copyIndex = 0;
    for (copyIndex = 0; copyIndex < count; copyIndex++)
    {
        dest[copyIndex] = source[copyIndex];
    }
}

void SendUCA0Data(uint8_t val)
{
    while (!(IFG2 & UCA0TXIFG));              // USCI_A0 TX buffer ready?
    UCA0TXBUF = val;
}

//******************************************************************************
// Device Initialization *******************************************************
//******************************************************************************
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

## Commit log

2025-04-16 re-init push
    [Analog_VFO.kicad_sch, Comm_Module.kicad_sch, FDC.kicad_pcb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]
2025-04-29 add SAKI80 support
    add SAKI80(AKA Super AKI-80) support,
    Modify Comand & intel HEX upload command to MiniLoader.
    [FDC_DMA.kicad_sch, Z80proto-SAKI80.kicad_sch, Z80proto-SAKI80_IOblock.kicad_sch]
2025-05-06 add misc.
    add SIO Hard flow control(but not work ...),
    add WAIT implement,
    add kermit implement(test).
    [Comm_Module.kicad_sch, Z80proto-SAKI80.kicad_sch, Z80proto-SAKI80_IOblock.kicad_sch]
2025-05-17 patch xymodem.c and command_x.asm
    add putchar_SIO0()/getchar_SIO0(), and SlowTick, SysTick
    fix file title, comments
    [Z80proto-SAKI80.kicad_sch]
2025-05-19 minor fix, and add lcdlib/xprintf
    add lcdlib, xprintf(debugging for xymodem)
    [xymodem.c]
2025-05-20 minor bug fix
    minor bug fix(double 'EI', etc.)
    add HARDWARE.md
    [xymodem.c]
2025-05-20 minor fix
    in xymodem.c, fix USE_LCD definition
    [xymodem.c]
2025-05-23 minor fix, debug xymodem.c
    use PIOA port for LCD, PPI is not used.
    debug xymodem.c. XMODEM128 function is almost work, but still buggy ...
    [xymodem.c]
2025-06-25 Switch zcc to sdcc
    Switch compiler
    (xymodem.c doesn't work)
    Add WAIT cycle circuit(HC191), still testing ...
    [Z80proto2.kicad_sch, Z80proto_ServMod.kicad_sch]
2025-07-02 Add Async. FIFO support(EXPERIMENTAL)
    Add FT245R Asynchronous FIFO support(EXPERIMENTAL)
    change environment MiniLoader(zcc->sdcc)
    [Comm_Module.kicad_sch, Z80proto-SAKI80.kicad_sch, Z80proto-SAKI80_AFIFO.kicad_sch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]
2025-07-07 Minor Fix
    MiniMon: Fix Async. FIFO framework use CRC8-CCITT.
2025-08-23 testmode(command_t) and tmhost update
    but still buggy ... FIFO purge timing ?
    [xymodem-suspend.c]
2025-09-18 EXPERIMENTAL : add reset* for FT245R
    add reset line ...
    [Comm_Module.kicad_sch]
